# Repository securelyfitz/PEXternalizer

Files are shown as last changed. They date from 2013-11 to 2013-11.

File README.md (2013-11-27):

PEXternalizer
=============

Pci Express eXternalizer lets you pull a PCIE1x port outside of your case using a usb3 cable

## Theory

PCI Express is a pretty awesome interface that excels at 'just working' no matter how bad a job your board/device was designed.

It automatically detects and enumerates devices, and automatically connects to them with as many lanes (X's) as possible at the highest speed possible (1.0=2.5ghz, 2.0=5ghz, 3.0=8ghz)

Due to this flexibility, you can plug a 1X card into a 16x slot, and vice versa, so long as you can physically make it fit (dremels, drills, saws, etc... now that's HARDWARE hacking)

PEXternalizer will allow you to plug one a tiny PCIE card into a slot on your board, and run a cable out of the box to a second PCB with a PCIE 1x slot on it.
The PCIE SIG specs external cabling for PCIE but it's too expensive. Luckily, there's a readily available inexpensive consumer cable rated for one 500mhz pair and 2 5ghz pairs : a USB 3.0 cable.

I designed it to fit in 50x50mm for DFRobot. They don't permit two boards in one design, so i just silkscreened a dotted line where you have to cut it in half. (more HARDWARE hacking)

##Using

* Disconnect power to your system
* Plug the PCIE fingers into a slot on your board.
* Plug a USB 3.0 A-Male to A-Male cable in the board (preferably 12", though i've gotten it to work up to 3')
* Run the cable wherever it needs to go and plug it in the other board.
* Plug your PCIe card in the slot. You might want to use zip ties to hold the board on to your card.
* Power up and cross your fingers!

##Building
Rev 0.9 is off to the fab, but of course not yet tested!

The Digikey BOM is saved in PEXternalizer-BOM.csv, you can upload or paste it's contents into the BOM wizard: https://www.digikey.com/classic/registereduser/BOMWizard.aspx

$7.01 + shipping

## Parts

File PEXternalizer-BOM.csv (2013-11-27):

Digi-Key Part Number | Manufacturer | Manufacturer Part Number | Customer Reference | Quantity 1 | Quantity 2 | Quantity 3 | Description | Comments | RoHS Status | Lead Free Status | REACH Status
609-1964-ND | FCI | 10018783-10010TLF |  | 1 | 0 | 0 | CONN PCI EXPRESS 36POS VERT PCB |  | RoHS Compliant | Lead free | Unaffected Jun-2011
A112643-ND | TE CONNECTIVITY AMP | 171826-4 |  | 1 | 0 | 0 | CONN HDR 4POS T/H R/A 2.5MM TIN |  | RoHS Compliant | Lead free | Unaffected Aug-2011
AP1084T33L-UDI-ND | DIODES INC | AP1084T33L-U |  | 1 | 0 | 0 | IC REG LDO 3.3V 5A TO220-3 |  | RoHS Compliant | Lead free | Unaffected Jun-2012
399-6601-ND | KEMET | ESK107M016AC3AA |  | 1 | 0 | 0 | CAP ALUM 100UF 16V 20% RADIAL |  | RoHS Compliant | Lead free | Unaffected Jun-2012
445-8441-ND | TDK CORPORATION | FK20X5R0J107M |  | 2 | 0 | 0 | CAP CER 100UF 6.3V 20% RADIAL |  | RoHS Compliant | Lead free | Not Available
609-4662-ND | FCI | 10117835-002LF |  | 2 | 0 | 0 | CONN USB 3.0 RCPT ST A R/A |  | RoHS Compliant | Lead free | Not Available

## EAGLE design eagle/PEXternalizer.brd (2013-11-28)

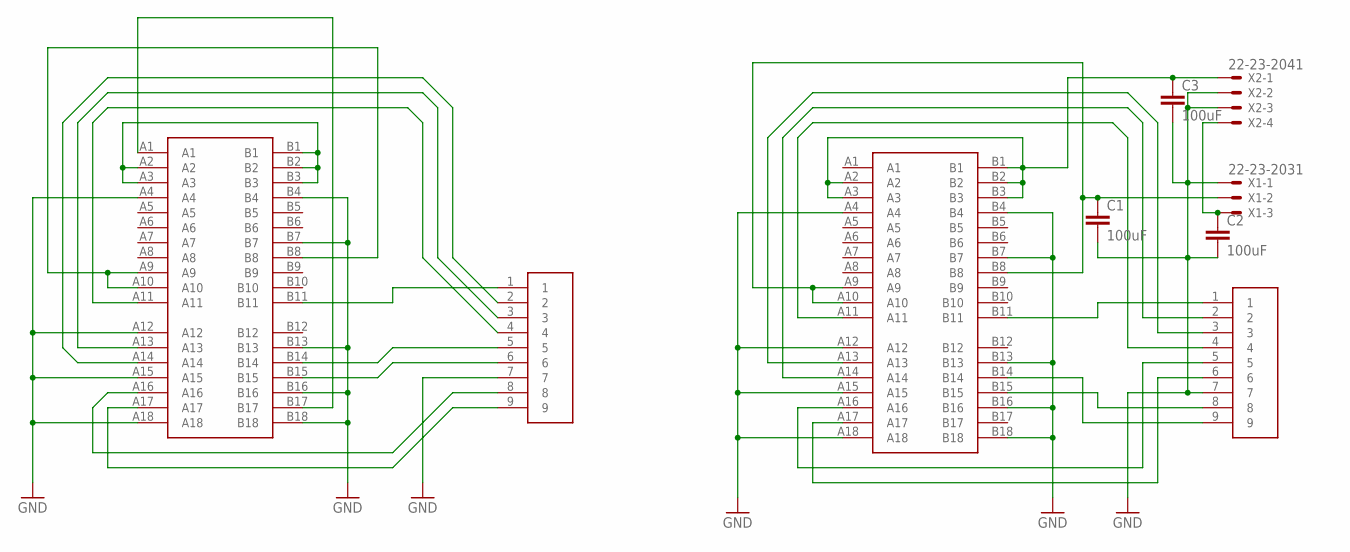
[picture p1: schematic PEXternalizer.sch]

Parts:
3.3V: PCI-E1XEDGE; PCI-E_36_EDGE
3.3V1: PCI-E1XCONN; PCI-E_36_CONN
C1, C2: 100uF; C5B2.5
C3: 100uF; C2.5-2
U$1, U$2: USB3FLAT; USB3_FLAT
X1: 22-23-2031
X2: 22-23-2041

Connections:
3.3V: 3.3V.A9, 3.3V.A10, 3.3V.B8
3.3V1: 3.3V1.A9, 3.3V1.A10, 3.3V1.B8, C1.1, X1.2
12V: 3.3V.A2, 3.3V.A3, 3.3V.B1, 3.3V.B2, 3.3V.B3
12V1: 3.3V1.A2, 3.3V1.A3, 3.3V1.B1, 3.3V1.B2, 3.3V1.B3, C3.1, X2.1
CLK2_N: 3.3V1.A14, U$2.2
CLK2_P: 3.3V1.A13, U$2.3
CLK_N: 3.3V.A13, U$1.3
CLK_P: 3.3V.A14, U$1.2
GND: 3.3V.A4, 3.3V.A12, 3.3V.A15, 3.3V.A18, 3.3V.B4, 3.3V.B7, 3.3V.B13, 3.3V.B16, 3.3V.B18, 3.3V1.A4, 3.3V1.A12, 3.3V1.A15, 3.3V1.A18, 3.3V1.B4, 3.3V1.B7, 3.3V1.B13, 3.3V1.B16, 3.3V1.B18, C1.2, C2.2, C3.2, U$1.7, U$2.7, X1.1, X2.2, X2.3
unnamed: 3.3V.B11, U$1.1
unnamed: 3.3V.A1, 3.3V.B17
unnamed: 3.3V1.A11, U$2.4
unnamed: 3.3V1.B11, U$2.1
unnamed: C2.1, X1.3, X2.4
unnamed: 3.3V.A11, U$1.4
RX1_N: 3.3V.A16, U$1.8
RX1_P: 3.3V.A17, U$1.9
RX2_N: 3.3V1.A16, U$2.5
RX2_P: 3.3V1.A17, U$2.6
TX1_N: 3.3V.B14, U$1.5
TX1_P: 3.3V.B15, U$1.6
TX2_N: 3.3V1.B15, U$2.8
TX2_P: 3.3V1.B14, U$2.9

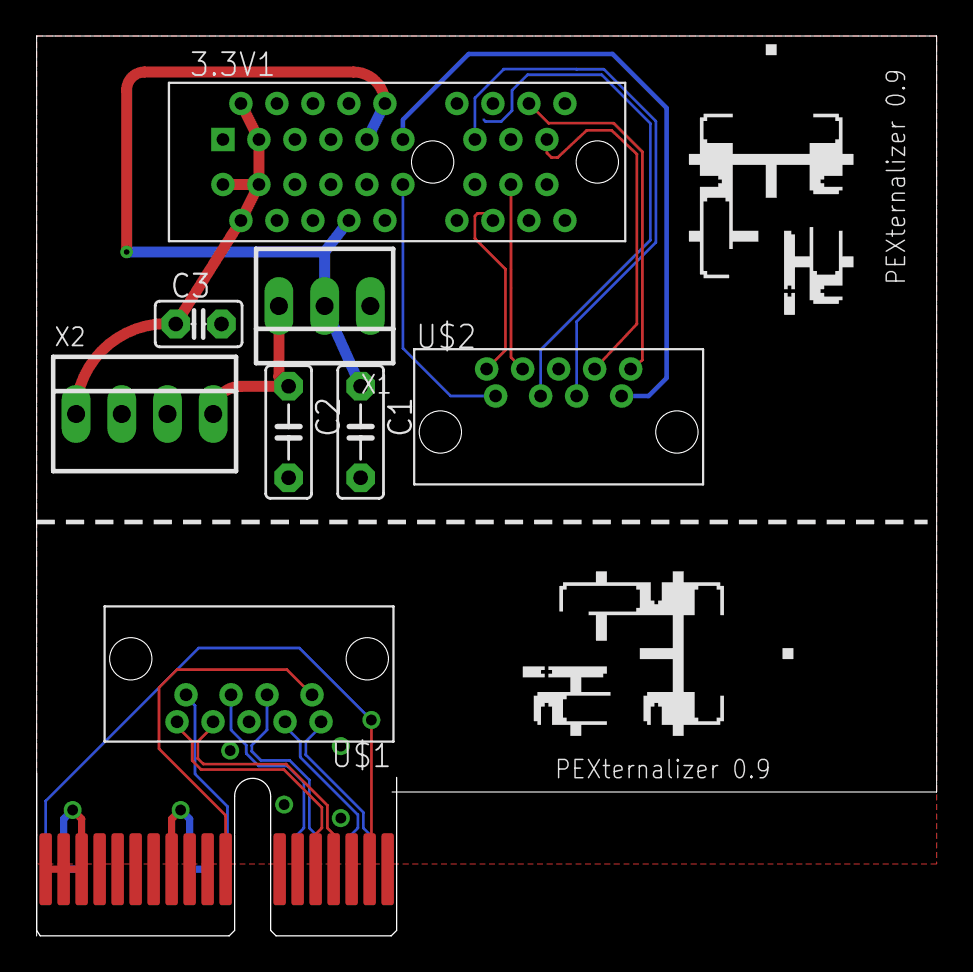
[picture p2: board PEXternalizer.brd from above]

Board: 2 copper layers, 50.0 x 50.0 mm, 11 parts (0 on the bottom side), 23 nets.

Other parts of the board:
U$3, U$4: SH

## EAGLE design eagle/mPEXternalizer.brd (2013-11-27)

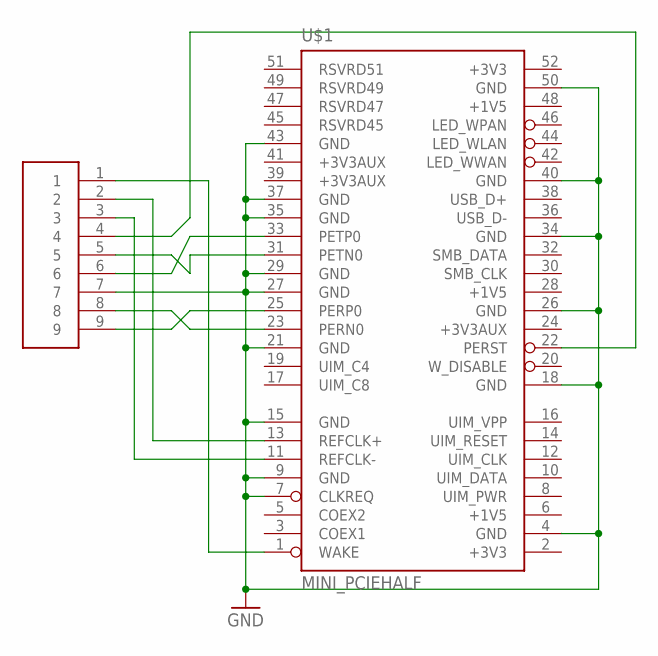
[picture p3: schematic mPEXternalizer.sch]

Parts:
U$1: MINI_PCIEHALF; MINI_PCIE_HALF
U$2: USB3FLAT; USB3_FLAT

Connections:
+1V5: U$1.6 (+1V5), U$1.28 (+1V5)
+3V3: U$1.2 (+3V3), U$1.52 (+3V3)
+3V3AUX: U$1.24 (+3V3AUX)
CK_N: U$1.11 (REFCLK-), U$2.3
CK_P: U$1.13 (REFCLK+), U$2.2
GND: U$1.4 (GND), U$1.7 (CLKREQ), U$1.9 (GND), U$1.15 (GND), U$1.18 (GND), U$1.21 (GND), U$1.26 (GND), U$1.27 (GND), U$1.29 (GND), U$1.34 (GND), U$1.35 (GND), U$1.37 (GND), U$1.40 (GND), U$1.43 (GND), U$1.50 (GND), U$1.HOLE1B (GND), U$1.HOLE1T (GND), U$1.HOLE2B (GND), U$1.HOLE2T (GND), U$2.7
unnamed: U$1.1 (WAKE), U$2.1
unnamed: U$1.22 (PERST), U$2.4
RX_N: U$1.25 (PERP0), U$2.9
RX_P: U$1.23 (PERN0), U$2.8
SMB_DATA: U$1.32 (SMB_DATA)
TX_N: U$1.31 (PETN0), U$2.5
TX_P: U$1.33 (PETP0), U$2.6
USB_D+: U$1.38 (USB_D+)

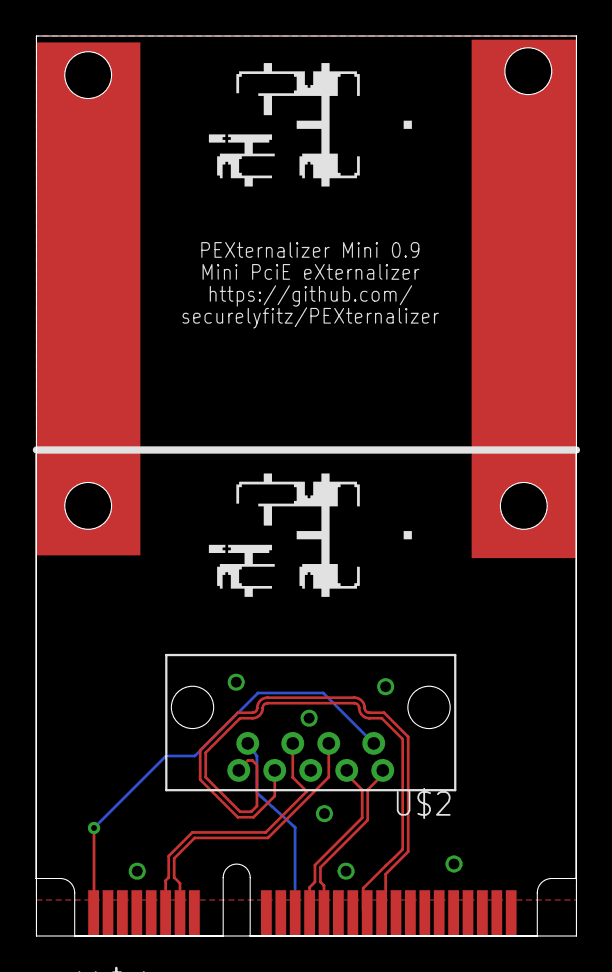
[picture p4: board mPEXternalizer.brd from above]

Board: 2 copper layers, 30.0 x 50.0 mm, 4 parts (0 on the bottom side), 11 nets.

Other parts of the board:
U$3, U$4: SH-HALFINCH

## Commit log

2013-11-27 Adding board files
    [PEXternalizer-BOM.csv, PEXternalizer.brd, PEXternalizer.sch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]
2013-11-27 fixing filenames
    [PEXternalizer.GBL, PEXternalizer.GBO, PEXternalizer.GBS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]
2013-11-27 silkscreen edits
    [PEXternalizer.brd]
2013-11-27 added usb2 connector
2013-11-27 Adding mini pci version
    [mPEXternalizer.GBL, mPEXternalizer.GBO, mPEXternalizer.GBS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]
2013-11-28 Fixed stupid board error.
    overlapping power plane traces fixed!
    [PEXternalizer.brd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]
